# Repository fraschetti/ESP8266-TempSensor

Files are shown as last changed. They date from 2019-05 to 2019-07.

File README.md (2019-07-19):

# ESP8266 Power efficient temperature sensor

Assembled sensor

## Sensor design and features
- Utilizes DHT22 temperature + humidity sensor
    - Changing to a different sensor should only require changes to a few lines of code
- OTA (Over The Air) firmware updates
    - No need to physically connect to device to flash new firmware	
- Utilizes InfluxDB time series DB for data logging
- Utilizes the board's deep sleep (low power) mode to minimize power consumption 
    - For maximum efficient/lowest power consumption, the board needs to be powered directly and not via the USB connector (which utilizes the on-board voltage regulator)
- Per device configuration for temperature and humidity adjustments
    - Adjustments can be made globally (it's all code) but for my purposes I used the ESP8266  WiFI adapter MAC address
    - It's reccomended to calibrate (adjust the software offsets) relative to known accurate sensors

## BOM (Bill of Materials)
### Sensor
- 1x ESP8266
    - The provided case leverages NodeMCU v3 w/o attached headers 
- 1x 1N5817 Schottky diode
- 1x 10kΩ resistor

### Case
- 4x M2x4 self tapping screws
- 2x M2x8 self tapping screws
- 1x M2 nylon washer (optional)
- 1x 3-wire Micro JST connector (optional to simplify disassembly/reassembly)

## Wiring diagram
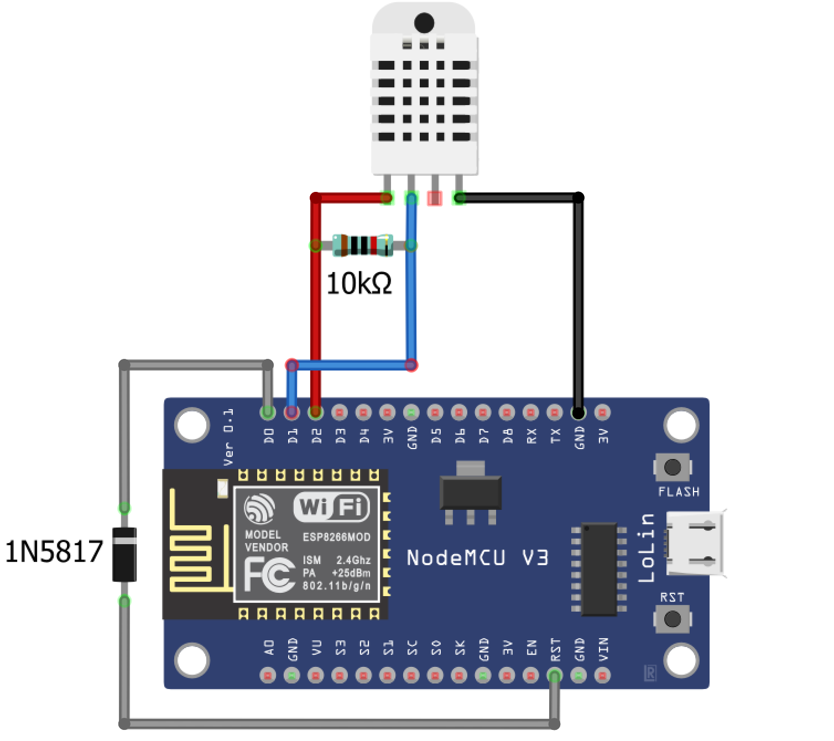
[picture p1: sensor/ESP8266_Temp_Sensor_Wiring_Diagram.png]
Wiring diagram


## Sensor OTA (Over The Air) update server

## Sensor case
- stl, step, and f3d models provided
- Flame retartent filament recommended
    - I personally use eSun ePC (Flame retardant level: UL94：V2) for electronics projects
- Remember to scale the 3D model to compensate for filament shrinkage
- This case relies on the ESP8266 NodeMCU v3 dimensions and a headerless (no pre-soldered pin headers) board. While headerless boards are more difficult to find, their use does allow for a much shorter, uniform, and convenient case height
- Board dimensions vary wildly between ESP8266 version and manufacturer. I highly reccomend comparing the dimensions of your board and screw hole sizes/locations to the 3D model to avoid wasting unnecessary time and filament
- Assembly
    - Use the 4x M2x4 screws to attach the ESP8266 to the case
    - Use the 2x M2x8 screws to attach the sensor lid to the case
    - If the sensor does not sit flush, use the nylon washer (any thin washer would do but I used a nylon washer as I had one available) to fill the empty space between the sensor and the lid
    - As long as the tolerances of your 3D print are within reason, the sliding lid should attach without force but should also not slide out on its own

Sensor case parts
Open sensor case

## Getting started

1. Install the ES8266 boards
    * Instructions [here](https://github.com/esp8266/Arduino#installing-with-boards-manager)
2. Select the ESP8266 board
    * Tools --> Boards --> *NodeMCU 1.0 (ESP-12E Module)*
3. Install the Adafruit DHT sensor library
    * Instructions [here](https://learn.adafruit.com/dht/using-a-dhtxx-sensor)
    * Don't forget to install both the *DHT sensor library* **and** the *Adafruit Unified Sensor* libraries
4. Locate the *writeNewDeviceSettings* function and make updates as necessary

These settings should be common across all your sensors.
```cpp
  char* otaUrl = "http://otaserverhostname:otaserverport/ota/tempsensor.bin"; //Blank if not using OTA updates
  short dhtPin = 5; //ESP8266 D1
  short dhtPowerPin = 4; //ESP8266 D2 (Not required if you use a power pin directly)
  char* wifiSSID = "yourwifissid";
  char* wifiPwd = "yourwifipwd";
  char* influxDBProtocol = "http";
  char* influxDBHost = "yourinfluxdbhost";
  int influxDBPort = 8086;
  char* influxDBDB = "sensordata";
  char* influxDBMeasurement = "temperature";
  short sendInterval = 60; //seconds
```

Each sensor must also have an entry to specify the device's ID and temperature/humidity adjustments.
To locate each sensor's MAC address, upload the sketch and observe the serial output.
```WiFi MAC Address: AA:AA:AA:AA:AA:AA```

```cpp
  if (mac_address == "AA:AA:AA:AA:AA:AA") {
    sensorTempAdjustment = 0.0;
    sensorHumdidityAdjustment = 0.0;
    deviceId = "SensorA";
  } else if (mac_address == "BB:BB:BB:BB:BB:BB") {
    sensorTempAdjustment = 0.0;
    sensorHumdidityAdjustment = 0.0;
    deviceId = "SensorB";
  }
```

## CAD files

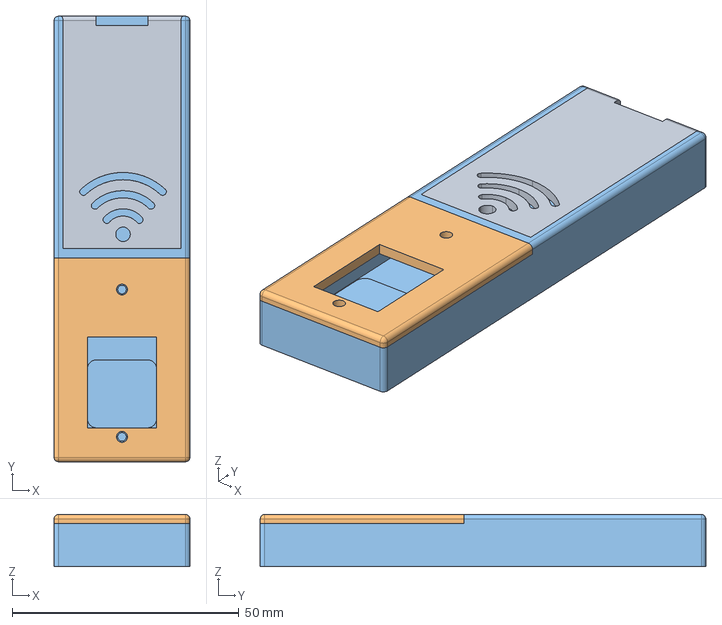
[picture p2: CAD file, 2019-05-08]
sensor-case/sensor_case.step
30.0 x 98.3 x 11.5 mm
Case Lid
SensorLid

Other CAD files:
sensor-case/sensor_case.f3d
sensor-case/sensor_case.stl

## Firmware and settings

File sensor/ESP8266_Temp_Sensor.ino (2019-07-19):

#include <Arduino.h>
#include <EEPROM.h>
#include <ESP8266WiFi.h>
#include <ESP8266HTTPClient.h>
#include <ESP8266httpUpdate.h>
#include "DHT.h"

//Release/Binary version (increase this with each new release)
#define FIRMWARE_VERSION 1

// DHT 22 sensor
#define DHTTYPE DHT22

#define MICROS 1000000

//Thread on deep sleep - GPIO16 + RESET diode - https://www.esp8266.com/viewtopic.php?f=160&t=13625&start=12
//ESP8266 D0  = 16 // 1N5817 Schottky diode (cathode to D0/16, anode to reset pin/pad)
//ESP8266 D1  = 5  // Data pin for DHT22 sensor (can be changed in the config below)
//ESP8266 D2  = 4  // Power pin for the DHT22 sensor (optional - can be changed in the config below)
//ESP8266 D3  = 0
//ESP8266 D4  = 2
//ESP8266 D5  = 14
//ESP8266 D6  = 12
//ESP8266 D7  = 13
//ESP8266 D8  = 15
//ESP8266 D9  = 3
//ESP8266 D10 = 1
//DHT22 1 = Power pin. Either tied directly to the 5v rail or a software controlled pin D2/4 (see above)
//DHT22 2 = Ground pin. Also use a 10k resistor to the 5v rail
//DHT22 3 = Not connected
//DHT22 4 = Data pin. Connected to D1/5 (see above)

//InfluxDB
#define INFLUXDB_URL    "$PROTOCOL$://$HOST$:$PORT$:/write?db=$DB$"
//https://docs.influxdata.com/influxdb/v1.6/write_protocols/line_protocol_reference/
String TEMP_DATA_TEMPLATE = "$measurement$,deviceid=$deviceid$ temperature=$temperature$,humidity=$humidity$,firmware=$firmware$,wifi_rssi=$wifi_rssi$";

// DHT sensor
float sensorPrimeTime = 2500; //Time required for sensor to be ready after power on

//WiFi
long wifiConnectStart;

//EEPROM storage struct for settings
struct {
  //Sanity valid for a valid struct (checking for a single integer isn't sufficient)
  char validation_string[6];

  short firmware_version;

  //OTA - Auto update URL
  char ota_url[128];

  //Sensor settings
  short dht_pin;
  short dht_power_pin;
  float sensor_temp_adjustment;
  float sensor_humidity_adjustment;

  //WiFi settings
  char wifi_ssid[64];
  char wifi_pwd[64];

  //InfluxDB settings
  char influxdb_protocol[6];
  char influxdb_host[64];
  int influxdb_port;
  char influxdb_db[32];
  char influxdb_measurement[32];
  char device_id[64];
  short send_interval; //seconds
}
localSettings;

void setup() {
  Serial.begin(115200);

  EEPROM.begin(512);

  long iterationStart = millis();

  Serial.println();
  Serial.println();
  Serial.println("-=ESP8266=-");
  Serial.println("Firmware version #: " + String(FIRMWARE_VERSION));
  Serial.println("Sketch date: " __DATE__ ", time: " __TIME__);
  Serial.printf("SDK version: %s\n", ESP.getSdkVersion());
  Serial.printf("Core Version: %s\n", ESP.getCoreVersion().c_str());
  Serial.printf("Boot Version: %u\n", ESP.getBootVersion());
  Serial.printf("Boot Mode: %u\n", ESP.getBootMode());
  Serial.printf("CPU Frequency: %u MHz\n", ESP.getCpuFreqMHz());
  Serial.printf("WiFi MAC Address: %s\n", WiFi.macAddress().c_str());
  Serial.printf("Reset reason: %s\n", ESP.getResetReason().c_str());

  Serial.println("-=Temperature Logger=-");
  bool readSettingsSuccess;
  readSettings(readSettingsSuccess);
  if (readSettingsSuccess)
    Serial.println("Successfully read and validated settings");
  else {
    Serial.println("Failed to read settings. Going into longest allowed deep sleep.");
    ESP.deepSleep(4294967295 * MICROS);
    return;
  }

  Serial.println("-=Settings=-");
  Serial.printf("Sensor data pin: %d\n", localSettings.dht_pin);
  Serial.printf("Sensor power pin: %d\n", localSettings.dht_power_pin);
  Serial.printf("OTA Update URL: %s\n", localSettings.ota_url);
  Serial.println("InfluxDB Protocol: " + String(localSettings.influxdb_protocol));
  Serial.println("InfluxDB Host: " + String(localSettings.influxdb_host));
  Serial.printf("InfluxDB Port: %d\n", localSettings.influxdb_port);
  Serial.println("InfluxDB DB: " + String(localSettings.influxdb_db));
  Serial.println("InfluxDB Measurement: " + String(localSettings.influxdb_measurement));
  Serial.println("DeviceID: " + String(localSettings.device_id));
  Serial.printf("Temperature adjustment: : %.2f\n", localSettings.sensor_temp_adjustment);
  Serial.printf("Humidity adjustment: : %.2f\n", localSettings.sensor_humidity_adjustment);

  //Init sensor power pin
  if (localSettings.dht_power_pin >= 0) {
    Serial.println("Energizing sensor power pin...");
    pinMode(localSettings.dht_power_pin, OUTPUT);
    digitalWrite(localSettings.dht_power_pin, HIGH);
  }

  DHT dht(localSettings.dht_pin, DHTTYPE);
  dht.begin();
  long sensorPrimeStart = millis();

  //Start the WiFi before priming the sensor to make good use of our time
  startWiFi();

  long remainingPrimeTime = sensorPrimeTime - (millis() - sensorPrimeStart);
  Serial.println("Priming sensor...");
  if (remainingPrimeTime > 0) {
    delay(remainingPrimeTime);
  }
  Serial.println("Sensor primed");

  connectToWiFi(1);

  if (WiFi.status() == WL_CONNECTED) {
    sendData(dht);
  }

  //Deenergize sensor power pin
  if (localSettings.dht_power_pin >= 0) {
    Serial.println("Denergizing sensor power pin...");
    digitalWrite(localSettings.dht_power_pin, LOW);
  }

  if (WiFi.status() == WL_CONNECTED)
    attemptFirmwareUpdate();

  stopWiFi();

  unsigned long iterationElapsed = millis() - iterationStart;
  Serial.printf("Iteration elapsed: %lums\n", iterationElapsed);

  long sleepMicros = (localSettings.send_interval * MICROS) - micros();
  if (sleepMicros <= 0) {
    Serial.println("No sleep needed. Restarting");
    ESP.restart();
  } else {
    int sleepSeconds = sleepMicros / MICROS;
    Serial.printf("Entering deep sleep (%dsecs)...\n", sleepSeconds);
    ESP.deepSleep(sleepMicros);
  }
}

void loop() {
}

void readSettings(bool &success) {
  Serial.println("Reading settings from EEPROM...");

  for (unsigned int t = 0; t < sizeof(localSettings); t++)
    *((char*)&localSettings + t) = EEPROM.read(t);

  boolean needNewSettings = true;

  if (String(localSettings.validation_string) != "Valid") {
    Serial.println("Validation of exisiting settings failed. Validation header missing. New settings needed.");
    needNewSettings = true;
  }

  if (!needNewSettings && localSettings.firmware_version != FIRMWARE_VERSION) {
    Serial.println("Validaton of existing settings failed. Config firmware version does not match current firmware version. New settings needed");
    needNewSettings = true;
  }

  if (needNewSettings) {
    Serial.println("New settings needed. Attempting to load new settings.");
    bool writeSettingsSuccess;
    writeNewDeviceSettings(writeSettingsSuccess);
    if (!writeSettingsSuccess) {
      success = false;
      return;
    }
  }

  //Validate WiFi settings
  String ssid = String(localSettings.wifi_ssid);
  String pwd = String(localSettings.wifi_pwd);
  if (ssid.length() == 0 || pwd.length() == 0) {
    Serial.println("Failed to validate WiFi settings");
    success = false;
    return;
  }

  //Validate InfluxDB settings
  String protocol = String(localSettings.influxdb_protocol);
  String host = String(localSettings.influxdb_host);
  String db = String(localSettings.influxdb_db);
  String measurement = String(localSettings.influxdb_measurement);
  String deviceid = String(localSettings.device_id);
  if (protocol.length() == 0 || host.length() == 0 || db.length() == 0
      || measurement.length() == 0 || deviceid.length() == 0) {
    Serial.println("Failed to validate InfluxDB settings");
    success = false;
    return;
  }

  success = true;
}

//Validate existing EEPROM settings are up to date and commit new settings if needed
void writeNewDeviceSettings(bool &success) {
  Serial.println("Attempting to write new device settings...");

  char* otaUrl = "http://otaserverhostname:otaserverport/ota/tempsensor.bin"; //Blank if not using OTA updates
  short dhtPin = 5; //ESP8266 D1
  short dhtPowerPin = 4; //ESP8266 D2 (Not required if you use a power pin directly)
  char* wifiSSID = "yourwifissid";
  char* wifiPwd = "yourwifipwd";
  char* influxDBProtocol = "http";
  char* influxDBHost = "yourinfluxdbhost";
  int influxDBPort = 8086;
  char* influxDBDB = "sensordata";
  char* influxDBMeasurement = "temperature";
  short sendInterval = 60; //seconds

  String mac_address = WiFi.macAddress().c_str();

  float sensorTempAdjustment;
  float sensorHumdidityAdjustment;
  String deviceId;

  if (mac_address == "AA:AA:AA:AA:AA:AA") {
    sensorTempAdjustment = 0.0;
    sensorHumdidityAdjustment = 0.0;
    deviceId = "SensorA";
  } else if (mac_address == "BB:BB:BB:BB:BB:BB") {
    sensorTempAdjustment = 0.0;
    sensorHumdidityAdjustment = 0.0;
    deviceId = "SensorB";
  } else if (mac_address == "CC:CC:CC:CC:CC:CC") {
    sensorTempAdjustment = 0.0;
    sensorHumdidityAdjustment = 0.0;
    deviceId = "SensorC";
  } else {
    Serial.printf("No configuration data found MAC address: %s\n", WiFi.macAddress().c_str());
    success = false;
    return;
  }

  //TODO bind config version to firmware version so they're updated together
  strcpy(localSettings.validation_string, "Valid"); //DO NOT CHANGE THIS
  localSettings.firmware_version = FIRMWARE_VERSION;

  //OTA URL
  strcpy(localSettings.ota_url, otaUrl);

  //Sensor settings
  localSettings.dht_pin = dhtPin;
  localSettings.dht_power_pin = dhtPowerPin;
  localSettings.sensor_temp_adjustment = sensorTempAdjustment;
  localSettings.sensor_humidity_adjustment = sensorHumdidityAdjustment;
  //WiFi settings
  strcpy(localSettings.wifi_ssid, wifiSSID);
  strcpy(localSettings.wifi_pwd, wifiPwd);
  //InfluxDB settings
  strcpy(localSettings.influxdb_protocol, influxDBProtocol);
  strcpy(localSettings.influxdb_host, influxDBHost);
  localSettings.influxdb_port = influxDBPort;
  strcpy(localSettings.influxdb_db, influxDBDB);
  strcpy(localSettings.influxdb_measurement, influxDBMeasurement);
  strcpy(localSettings.device_id, deviceId.c_str());
  localSettings.send_interval = sendInterval;

  Serial.println("Writing settings to EEPROM...");

  for (unsigned int t = 0; t < sizeof(localSettings); t++)
    EEPROM.write(t, *((char*)&localSettings + t));

  EEPROM.commit();

  success = true;
}

int maxWiFiConnectAttemps = 2;
void connectToWiFi(int attemptNumber) {
  Serial.println("Waiting for WiFi connection...");

  int maxWaitMs = 15 * 1000;
  unsigned long waitAbortMs = millis() + maxWaitMs;
  while (WiFi.status() != WL_CONNECTED) {
    if (millis() >= waitAbortMs) {
      break;
    }
    delay(250);
  }

  if (WiFi.status() == WL_CONNECTED) {
    IPAddress localIP = WiFi.localIP();
    Serial.printf("Connected to WiFi - IP: %d.%d.%d.%d\n", localIP[0], localIP[1], localIP[2], localIP[3]);
    Serial.printf("WiFi connection time %lums\n", millis() - wifiConnectStart);
    Serial.printf("WiFi signal stregnth: %d dBm\n",  WiFi.RSSI());
    Serial.printf("WiFi channel: %d\n",  WiFi.channel());
  } else if (attemptNumber >= maxWiFiConnectAttemps) {
    Serial.println("Final attempt to connect to WiFi failed.");
  } else {
    Serial.println("Failed to connect to WiFi. Retrying.");
    stopWiFi();
    startWiFi();
    connectToWiFi(attemptNumber + 1);
  }
}

void startWiFi() {
  Serial.println("Waking WiFi...");
  WiFi.forceSleepWake();
  delay(1);

  Serial.println("Connecting to WiFi network...");

  WiFi.hostname("Sensor - " + String(localSettings.device_id));
  WiFi.mode(WIFI_STA);
  WiFi.persistent(false); //Eliminate flash writes
  WiFi.setAutoConnect(false);
  WiFi.setAutoReconnect(false);
  WiFi.begin(localSettings.wifi_ssid, localSettings.wifi_pwd);
  wifiConnectStart = millis();

  //DO NOT USE WiFi.waitForConnectResult() as current implementations use large timeouts
}

// https://github.com/esp8266/Arduino/issues/644
void stopWiFi() {
  Serial.println("Putting WiFi to sleep...");

  WiFi.disconnect();
  delay(1000); //See: https://github.com/esp8266/Arduino/issues/4082
  WiFi.mode(WIFI_OFF);

  WiFi.forceSleepBegin();
  delay(1);
}

void sendData(DHT &dht) {
  Serial.println("-=Send Data Start=-");

  String deviceIdFormatted = localSettings.device_id;
  formatLineProtocol(deviceIdFormatted);

  String temp_influx_url = INFLUXDB_URL;
  temp_influx_url.replace("$PROTOCOL$", localSettings.influxdb_protocol);
  temp_influx_url.replace("$HOST$", localSettings.influxdb_host);
  temp_influx_url.replace("$PORT$", String(localSettings.influxdb_port));
  temp_influx_url.replace("$DB$", localSettings.influxdb_db);

  float temp_data[2];
  readTemp(dht, temp_data);
  float humidity_data = temp_data[0];
  float temperature_data = temp_data[1];

  if (isnan(humidity_data)
      || humidity_data <= 0
      || isnan(temperature_data)
      || temperature_data <= 0) {
    Serial.println("-=Send Data End=-");
    return;
  }

  String temp_data_str = TEMP_DATA_TEMPLATE;
  temp_data_str.replace("$measurement$", localSettings.influxdb_measurement);
  temp_data_str.replace("$deviceid$", deviceIdFormatted);
  temp_data_str.replace("$temperature$", String(temperature_data, 2));
  temp_data_str.replace("$humidity$", String(humidity_data, 2));
  temp_data_str.replace("$firmware$", String(FIRMWARE_VERSION));
  temp_data_str.replace("$wifi_rssi$", String(WiFi.RSSI()));

  Serial.println("InfluxDB URL: " + temp_influx_url);
  Serial.println("InfluxDB Record: " + temp_data_str);

  HTTPClient http;
  http.begin(temp_influx_url);

  int statusCode = http.POST(temp_data_str);
  String rspBody = http.getString();

  Serial.printf("Response Status Code: %d (Success = 204)\n", statusCode);

  if (rspBody != NULL) {
    rspBody.trim();

    if (rspBody.length() > 0) {
      Serial.println("Response Body: " + rspBody);
    }
  }

  http.end();
  Serial.println("-=Send Data End=-");
}

void readTemp(DHT &dht, float temp_data[]) {
  // Grab the current state of the sensor,
  // allowing for a couple of read errors (it happens from time to time)
  long startRead = millis();
  Serial.println("Reading temperature...");
  for (int i = 0; i < 10; i++) {
    float temperature_data = dht.readTemperature(true);
    float humidity_data = dht.readHumidity();


    if (!isnan(temperature_data) && !isnan(humidity_data)) {
      Serial.printf("Sensor read elapsed: %lums\n", millis() - startRead);
      Serial.printf("Orig Temperature: %.2f\n", temperature_data);
      Serial.printf("Orig Humidity: %.2f\n", humidity_data);

      temperature_data += localSettings.sensor_temp_adjustment;
      humidity_data += localSettings.sensor_humidity_adjustment;

      Serial.printf("Adjusted Temperature: %.2f\n", temperature_data);
      Serial.printf("Adjusted Humidity: %.2f\n", humidity_data);

      temp_data[0] = humidity_data;
      temp_data[1] = temperature_data;

      return;
    }
    delay(2000);
  }

  Serial.println("Failed to read temperature & humidity data.");

  temp_data[0] = 0;
  temp_data[1] = 0;
}

void formatLineProtocol(String &input) {
  input.replace(",", "\\,");
  input.replace("=", "\\=");
  input.replace(" ", "\\ ");
  input.replace("\"", "\\\"");
}

void attemptFirmwareUpdate() {
  Serial.println("Checking for firmware update...");

  String OTAUrl = String(localSettings.ota_url);
  if (OTAUrl == NULL || OTAUrl.length() == 0) {
    Serial.println("No configured OTA update URL. Skipping update check.");
    return;
  }

  OTAUrl = OTAUrl + "?deviceid=" + urlencode(String(localSettings.device_id))
           + "&firmware_version=" + String(FIRMWARE_VERSION)
           + "&temp_adjustment=" + String(localSettings.sensor_temp_adjustment, 2)
           + "&humidity_adjustment=" + String(localSettings.sensor_humidity_adjustment, 2)
           + "&wifi_rssi=" + String(WiFi.RSSI());


  //TODO call handleUpdate directly to pass in a HTTPClient with manual timeouts?
  t_httpUpdate_return ret = ESPhttpUpdate.update(OTAUrl, String(FIRMWARE_VERSION));
  Serial.println("Update check complete.");

  switch (ret) {
    case HTTP_UPDATE_FAILED:
      Serial.printf("Auto-update - Failed - Error(%d): %s\n", ESPhttpUpdate.getLastError(), ESPhttpUpdate.getLastErrorString().c_str());
      break;

    case HTTP_UPDATE_NO_UPDATES:
      Serial.println("Auto-update - No update required");
      break;

    case HTTP_UPDATE_OK:
      //This path will apparently never actually be called (auto reset is part of the update)
      Serial.println("Auto-update - Success");
      break;
  }
}

//Borrowed from https://github.com/zenmanenergy/ESP8266-Arduino-Examples/blob/master/helloWorld_urlencoded/urlencode.ino
//I needed something quick to get a job done but haven't fully vetted this logic
String urlencode(String str)
{
  String encodedString = "";
  char c;
  char code0;
  char code1;
  for (unsigned int i = 0; i < str.length(); i++) {
    c = str.charAt(i);
    if (c == ' ') {
      encodedString += '+';
    } else if (isalnum(c)) {
      encodedString += c;
    } else {
      code1 = (c & 0xf) + '0';
      if ((c & 0xf) > 9) {
        code1 = (c & 0xf) - 10 + 'A';
      }
      c = (c >> 4) & 0xf;
      code0 = c + '0';
      if (c > 9) {
        code0 = c - 10 + 'A';
      }
      encodedString += '%';
      encodedString += code0;
      encodedString += code1;
    }
    yield();
  }
  return encodedString;
}

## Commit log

2019-05-08 Creating sensor stub file
2019-05-08 Initial sensor commit
2019-05-08 Creating sensor case stub
    [sensor_case.stl]
2019-05-08 Initial sensor case commit
    [sensor_case.f3d, sensor_case.step, sensor_case.stl]
2019-05-18 Adding wiring diagrams
    [ESP8266_Temp_Sensor_Wiring_Diagram.fzz]
2019-05-19 Uploading 3D printed case images
2019-05-19 Resizing case images
2019-05-19 Broke apart the stl to make it directly printable
    [sensor_case.stl]
